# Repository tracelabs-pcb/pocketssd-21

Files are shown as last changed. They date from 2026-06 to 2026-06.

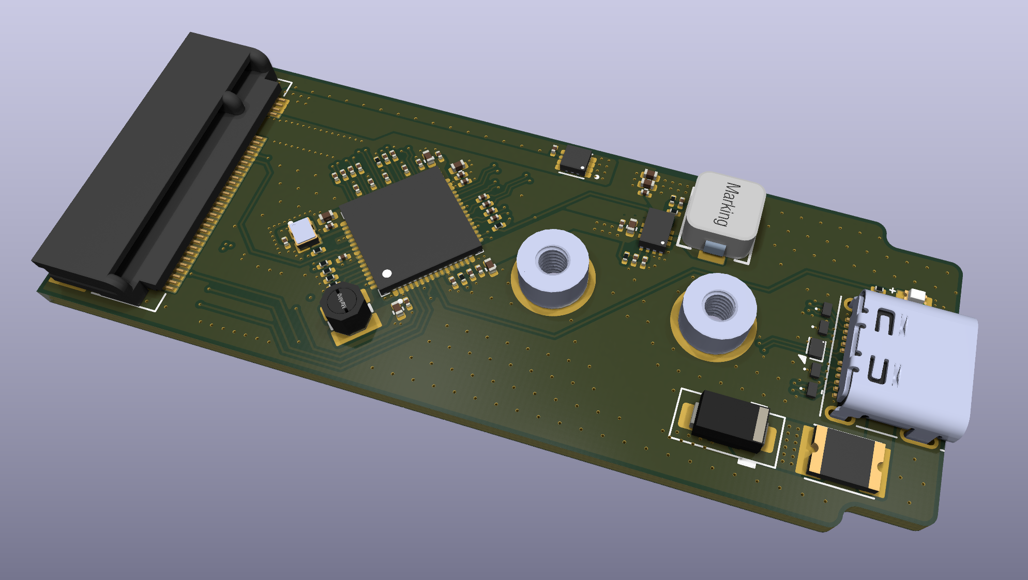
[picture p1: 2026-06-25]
screenshots/3D View Pocket SSD.png

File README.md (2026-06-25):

# PocketSSD-21 — Kompakter USB 3.2 Gen2 NVMe Adapter

**Status: PCB-Design abgeschlossen — unbestückt**  
**Tool:** KiCad | **Layer:** 6-Layer | **Hersteller-ready:** Ja

---

## Projektbeschreibung

Kompakter USB 3.2 Gen2 zu NVMe M.2 Bridge-Adapter auf Basis des JMS583.
Designed für maximale Datenrate bei minimaler Baugröße. 
6-Layer-Stackup (JLC06161H-1080) für saubere Signalintegrität auf 
USB 3.2 Gen2 SuperSpeed+ und PCIe-Leiterbahnen.

**Besonderheiten:**
- USB 3.2 Gen2 (10 Gbit/s) über USB-C
- NVMe M.2 (PCIe Gen3 ×2) Unterstützung
- JMS583 Bridge-Controller
- Differentielle Paare mit kontrollierter Impedanz
- Kompaktes Format, direkt steckbar

---

## Hardware

| Komponente | Beschreibung |
|---|---|
| Bridge-Controller | JMS583 (USB 3.2 Gen2 ↔ PCIe Gen3 ×2) |
| Schnittstelle Host | USB-C (USB 3.2 Gen2, 10 Gbit/s) |
| Schnittstelle Storage | M.2 Key-M (NVMe, PCIe Gen3 ×2) |
| Stackup | 6-Layer (JLC06161H-1080) |
| Tool | KiCad |

---

## PCB

- 6-Layer Stackup für kontrollierte Impedanz
- Differentielle Paare (USB SS+/−, PCIe TX/RX) mit Längen-Matching
- Dedizierte GND-Planes zur Schirmung
- Hierarchisches Schematic über fünf Sheets

---

## Ausschlüsse

Portfolioprojekt — kein Serienprodukt, kein CE/EMV.

---

## Dateien in diesem Repository

- `/kicad/` — KiCad Projektdateien
- `/screenshots/` — PCB- und Schematic-Ansichten

---

> Entwickelt von [Shawn Schneider](https://tracelabs-pcb.de)  
> — PCB-Design & Lötservice, Wolfsburg

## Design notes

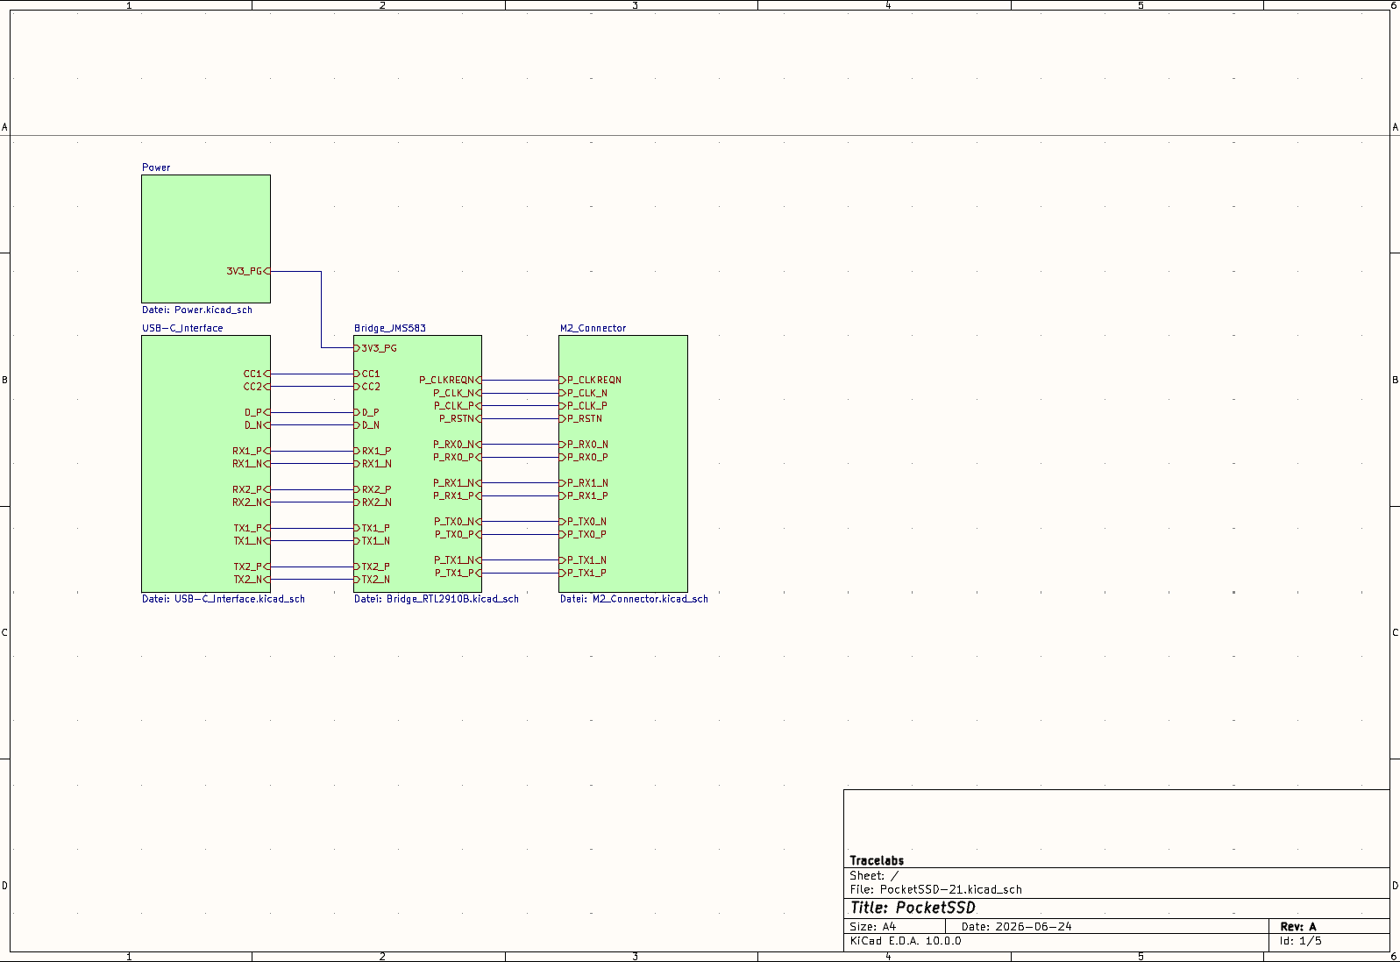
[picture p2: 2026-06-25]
screenshots/Top-Level-Schematic Pocket SSD.png

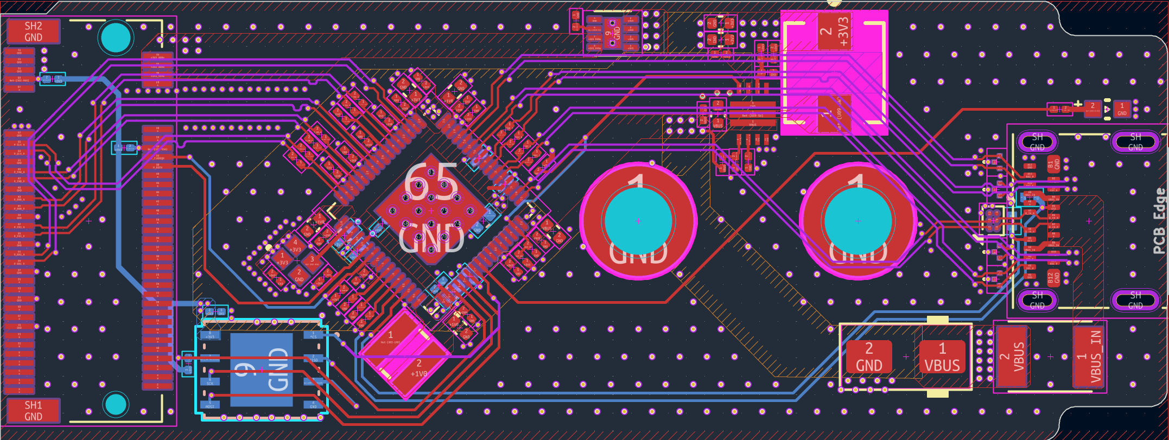
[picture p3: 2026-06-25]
screenshots/PCB Pocket SSD.png

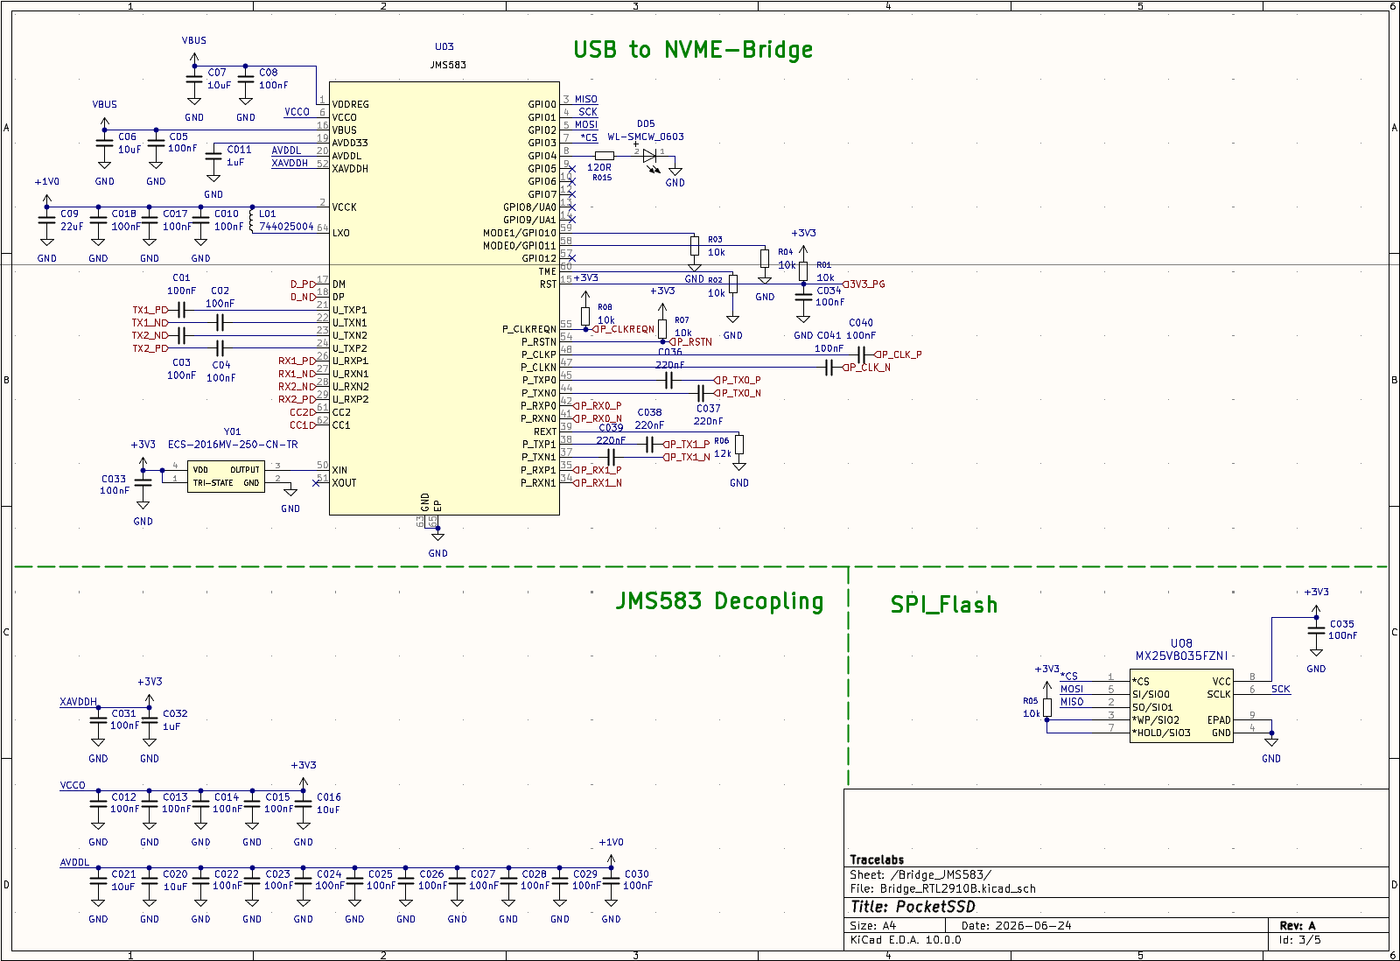
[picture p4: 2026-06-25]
screenshots/Hierarchal Sheet USB-NVMe-Bridge.png

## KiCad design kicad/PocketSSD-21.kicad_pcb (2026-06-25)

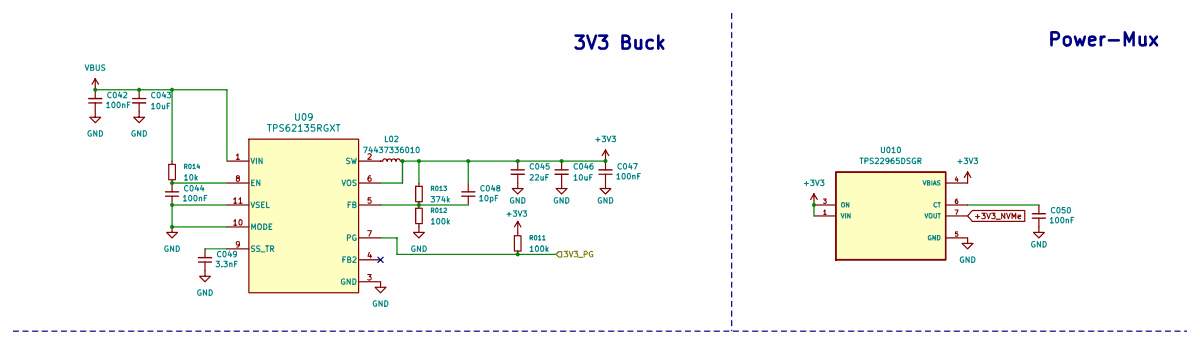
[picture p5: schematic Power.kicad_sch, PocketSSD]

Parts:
C042, C044, C047, C050: 100nF; C_0201_0603Metric
C043, C046: 10uF; C_0402_1005Metric
C045: 22uF; C_0402_1005Metric
C048: 10pF; C_0201_0603Metric
C049: 3.3nF; C_0201_0603Metric
L02: 74437336010; WE-LHMI_5030
R011, R012: 100k; R_0201_0603Metric
R013: 374k; R_0201_0603Metric
R014: 10k; R_0201_0603Metric
U09: TPS62135RGXT; RGX0011A
U010: TPS22965DSGR; SON50P200X200X80-9N

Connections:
+3V3: C045.1, C046.1, C047.2, C048.2, L02.2, R011.1, R013.1, U09.6 (VOS), U010.1 (VIN), U010.2 (VIN), U010.3 (ON), U010.4 (VBIAS); also elsewhere on the board
+3V3_NVMe: U010.7 (VOUT), U010.8 (VOUT); also elsewhere on the board
/Bridge_JMS583/3V3_PG: R011.2, U09.7 (PG); also elsewhere on the board
GND: C042.1, C043.2, C044.1, C045.2, C046.2, C047.1, C049.1, C050.1, R012.2, U09.3 (GND), U09.10 (MODE), U09.11 (VSEL), U010.5 (GND), U010.9 (GND), U010.9_1 (GND), U010.9_2 (GND); also elsewhere on the board
unnamed: C044.2, R014.2, U09.8 (EN)
unnamed: C048.1, R012.1, R013.2, U09.5 (FB)
unnamed: C049.2, U09.9 (SS_TR)
unnamed: L02.1, U09.2 (SW)
unnamed: C050.2, U010.6 (CT)
VBUS: C042.2, C043.1, R014.1, U09.1 (VIN); also elsewhere on the board

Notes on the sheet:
Power-Mux
3V3 Buck

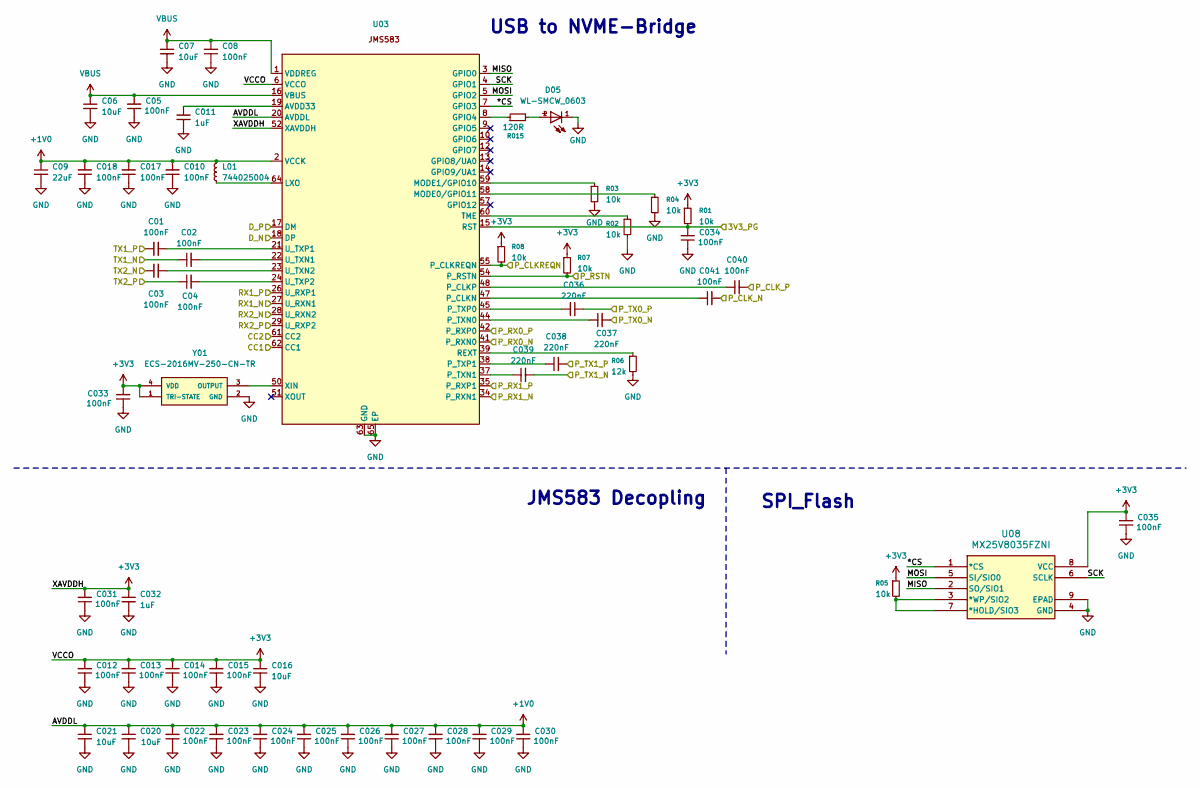
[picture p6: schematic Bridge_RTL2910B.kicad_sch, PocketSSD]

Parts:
C01, C02, C03, C04, C05, C08, C010, C012, C013, C014, C015, C017, C018, C022, C023, C024, C025, C026, C027, C028, C029, C030, C031, C033, C034, C035, C040, C041: 100nF; C_0201_0603Metric
C06, C07, C016, C020, C021: 10uF; C_0402_1005Metric
C09: 22uF; C_0402_1005Metric
C011, C032: 1uF; C_0402_1005Metric
C036, C037, C038, C039: 220nF; C_0201_0603Metric
D05: WL-SMCW_0603
L01: 744025004; WE-TPC_2828
R01, R02, R03, R04, R05, R07, R08: 10k; R_0201_0603Metric
R06: 12k; R_0201_0603Metric
R015: 120R; R_0201_0603Metric
U03: IC_KSZ8794CNXCC-TR
U08: MX25V8035FZNI; WSON8_6X5_MAC
Y01: ECS-2016MV-250-CN-TR; OSC_ECS-1618-300-BN-TR

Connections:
+1V0: C09.1, C010.2, C017.2, C018.2, C020.1, C021.1, C022.2, C023.2, C024.2, C025.2, C026.2, C027.2, C028.2, C029.2, C030.2, L01.2, U03.2 (VCCK), U03.20 (AVDDL), U03.25 (U_AVDDL), U03.30 (U_AVDDL), U03.31 (VCCK), U03.33 (P_AVDDL), U03.36 (P_AVDDL), U03.40 (P_AVDDL), U03.43 (P_AVDDL), U03.46 (C_AVDDL), U03.49 (P_AVDDL), U03.53 (VCCK)
+3V3: C012.2, C013.2, C014.2, C015.2, C016.1, C031.2, C032.1, C033.2, C035.2, R01.1, R05.1, R07.1, R08.1, U03.6 (VCCO), U03.11 (VCCO), U03.32 (VCCO), U03.52 (XAVDDH), U03.56 (VCCO), U08.8 (VCC), Y01.1 (TRI-STATE), Y01.4 (VDD); also elsewhere on the board
/Bridge_JMS583/3V3_PG: C034.2, R01.2, U03.15 (RST); also elsewhere on the board
/Bridge_JMS583/*CS: U03.7 (GPIO3), U08.1 (*CS)
/Bridge_JMS583/CC1: U03.62 (CC1); also elsewhere on the board
/Bridge_JMS583/CC2: U03.61 (CC2); also elsewhere on the board
/Bridge_JMS583/D_N: U03.18 (DP); also elsewhere on the board
/Bridge_JMS583/D_P: U03.17 (DM); also elsewhere on the board
/Bridge_JMS583/MISO: U03.3 (GPIO0), U08.2 (SO/SIO1)
/Bridge_JMS583/MOSI: U03.5 (GPIO2), U08.5 (SI/SIO0)
/Bridge_JMS583/P_CLKREQN: R08.2, U03.55 (P_CLKREQN); also elsewhere on the board
/Bridge_JMS583/P_CLK_N: C041.2; also elsewhere on the board
/Bridge_JMS583/P_CLK_P: C040.2; also elsewhere on the board
/Bridge_JMS583/P_RSTN: R07.2, U03.54 (P_RSTN); also elsewhere on the board
/Bridge_JMS583/P_RX0_N: U03.41 (P_RXN0); also elsewhere on the board
/Bridge_JMS583/P_RX0_P: U03.42 (P_RXP0); also elsewhere on the board
/Bridge_JMS583/P_RX1_N: U03.34 (P_RXN1); also elsewhere on the board
/Bridge_JMS583/P_RX1_P: U03.35 (P_RXP1); also elsewhere on the board
/Bridge_JMS583/P_TX0_N: C037.2; also elsewhere on the board
/Bridge_JMS583/P_TX0_P: C036.2; also elsewhere on the board
/Bridge_JMS583/P_TX1_N: C039.2; also elsewhere on the board
/Bridge_JMS583/P_TX1_P: C038.2; also elsewhere on the board
/Bridge_JMS583/RX1_N: U03.27 (U_RXN1); also elsewhere on the board
/Bridge_JMS583/RX1_P: U03.26 (U_RXP1); also elsewhere on the board
/Bridge_JMS583/RX2_N: U03.28 (U_RXN2); also elsewhere on the board
/Bridge_JMS583/RX2_P: U03.29 (U_RXP2); also elsewhere on the board
/Bridge_JMS583/SCK: U03.4 (GPIO1), U08.6 (SCLK)
/Bridge_JMS583/TX1_N: C02.1; also elsewhere on the board
/Bridge_JMS583/TX1_P: C01.1; also elsewhere on the board
/Bridge_JMS583/TX2_N: C03.1; also elsewhere on the board
/Bridge_JMS583/TX2_P: C04.1; also elsewhere on the board
GND: C05.1, C06.2, C07.2, C08.1, C09.2, C010.1, C011.2, C012.1, C013.1, C014.1, C015.1, C016.2, C017.1, C018.1, C020.2, C021.2, C022.1, C023.1, C024.1, C025.1, C026.1, C027.1, C028.1, C029.1, C030.1, C031.1, C032.2, C033.1, C034.1, C035.1, D05.1, R02.2, R03.2, R04.2, R06.2, U03.63 (GND), U03.65 (EP), U03.66 (GND), U03.67 (GND), U03.68 (GND), U03.69 (GND), U03.70 (GND), U03.71 (GND), U03.72 (GND), U03.73 (GND), U03.74 (GND), U03.75 (GND), U03.76 (GND), U03.77 (GND), U03.78 (GND), U03.79 (GND), U03.80 (GND), U03.81 (GND), U08.4 (GND), U08.9 (EPAD), Y01.2 (GND); also elsewhere on the board
unnamed: D05.2, R015.2
unnamed: C011.1, U03.19 (AVDD33)
unnamed: R015.1, U03.8 (GPIO4)
unnamed: L01.1, U03.64 (LXO)
unnamed: R04.1, U03.58 (MODE0/GPIO11)
unnamed: R03.1, U03.59 (MODE1/GPIO10)
unnamed: C041.1, U03.47 (P_CLKN)
unnamed: C040.1, U03.48 (P_CLKP)
unnamed: C037.1, U03.44 (P_TXN0)
unnamed: C039.1, U03.37 (P_TXN1)
unnamed: C036.1, U03.45 (P_TXP0)
unnamed: C038.1, U03.38 (P_TXP1)
unnamed: R06.1, U03.39 (REXT)
unnamed: R02.1, U03.60 (TME)
unnamed: C02.2, U03.22 (U_TXN1)
unnamed: C03.2, U03.23 (U_TXN2)
unnamed: C01.2, U03.21 (U_TXP1)
unnamed: C04.2, U03.24 (U_TXP2)
unnamed: U03.50 (XIN), Y01.3 (OUTPUT)
unnamed: R05.2, U08.3 (*WP/SIO2), U08.7 (*HOLD/SIO3)
VBUS: C05.2, C06.1, C07.1, C08.2, U03.1 (VDDREG), U03.16 (VBUS); also elsewhere on the board

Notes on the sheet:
JMS583 Decopling
USB to NVME-Bridge
SPI_Flash

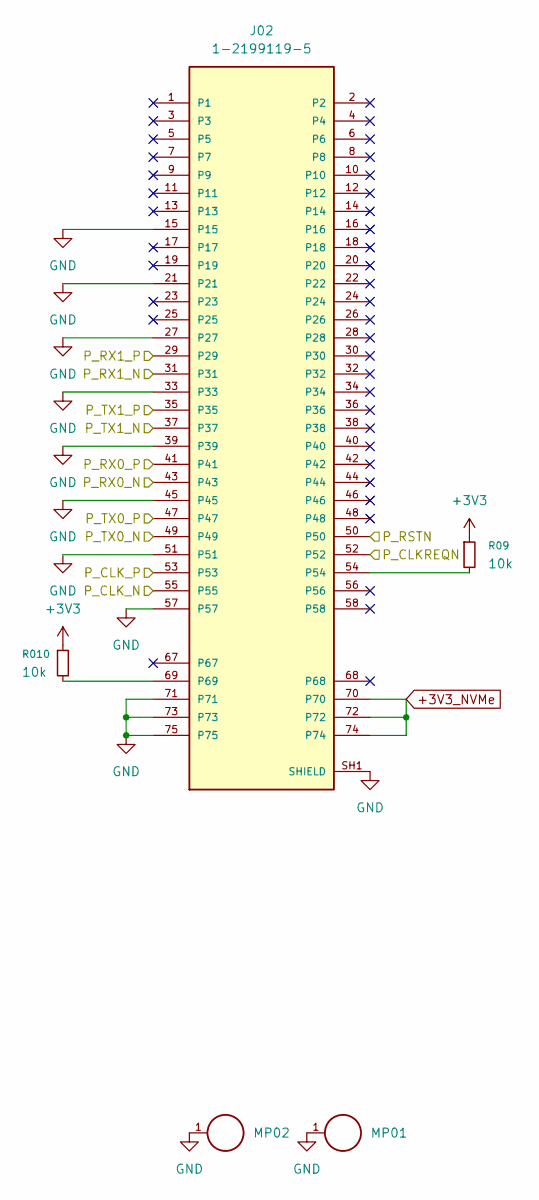
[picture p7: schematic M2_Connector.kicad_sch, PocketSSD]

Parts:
J02: 1-2199119-5; TE_1-2199119-5; DigiKey_Part_Number A115902CT-ND
MP01, MP02: M2.5 x 2.5mm; WA-SMSI_9774025151; PART-NUMBER 9774025151R
R09, R010: 10k; R_0201_0603Metric

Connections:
+3V3: R09.1, R010.1; also elsewhere on the board
+3V3_NVMe: J02.70, J02.72, J02.74; also elsewhere on the board
/Bridge_JMS583/P_CLKREQN: J02.52; also elsewhere on the board
/Bridge_JMS583/P_CLK_N: J02.55; also elsewhere on the board
/Bridge_JMS583/P_CLK_P: J02.53; also elsewhere on the board
/Bridge_JMS583/P_RSTN: J02.50; also elsewhere on the board
/Bridge_JMS583/P_RX0_N: J02.43; also elsewhere on the board
/Bridge_JMS583/P_RX0_P: J02.41; also elsewhere on the board
/Bridge_JMS583/P_RX1_N: J02.31; also elsewhere on the board
/Bridge_JMS583/P_RX1_P: J02.29; also elsewhere on the board
/Bridge_JMS583/P_TX0_N: J02.49; also elsewhere on the board
/Bridge_JMS583/P_TX0_P: J02.47; also elsewhere on the board
/Bridge_JMS583/P_TX1_N: J02.37; also elsewhere on the board
/Bridge_JMS583/P_TX1_P: J02.35; also elsewhere on the board
GND: J02.15, J02.21, J02.27, J02.33, J02.39, J02.45, J02.51, J02.57, J02.71, J02.73, J02.75, J02.SH1 (SHIELD), J02.SH2 (SHIELD), MP01.1, MP02.1; also elsewhere on the board
unnamed: J02.54, R09.2
unnamed: J02.69, R010.2

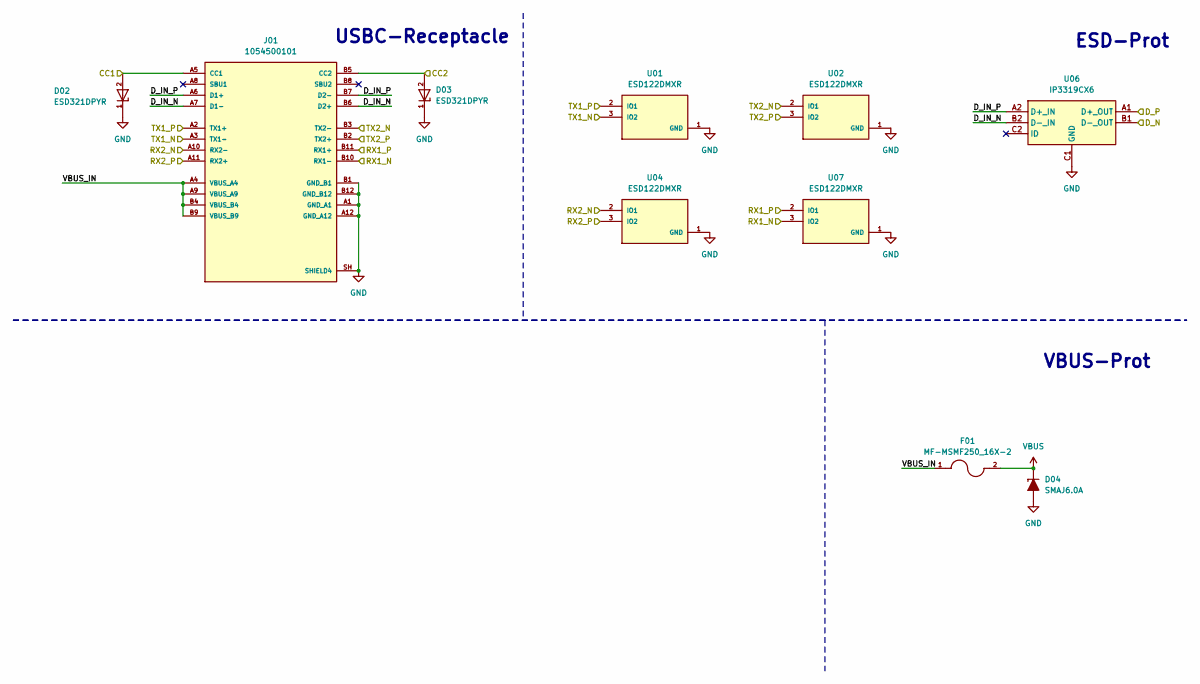
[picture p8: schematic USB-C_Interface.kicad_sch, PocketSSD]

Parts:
D02, D03: ESD321DPYR; TVS_ESD321DPYR; PARTREV B
D04: SMAJ6.0A; D_SMA
F01: MF-MSMF250_16X-2; FUSER_MF-MSMF250_16X-2
J01: 1054500101; USB_C_Receptacle_Molex_105450-0101; PARTREV A7
U01, U02, U04, U07: ESD122DMXR; IC_ESD122DMXR; PARTREV A
U06: IP3319CX6; WLCSP-6_1.4x1.0mm_P0.4mm

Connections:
/Bridge_JMS583/CC1: D02.2, J01.A5 (CC1); also elsewhere on the board
/Bridge_JMS583/CC2: D03.2, J01.B5 (CC2); also elsewhere on the board
/Bridge_JMS583/D_N: U06.B1 (D-_OUT); also elsewhere on the board
/Bridge_JMS583/D_P: U06.A1 (D+_OUT); also elsewhere on the board
/Bridge_JMS583/RX1_N: J01.B10 (RX1-), U07.3 (IO2); also elsewhere on the board
/Bridge_JMS583/RX1_P: J01.B11 (RX1+), U07.2 (IO1); also elsewhere on the board
/Bridge_JMS583/RX2_N: J01.A10 (RX2-), U04.2 (IO1); also elsewhere on the board
/Bridge_JMS583/RX2_P: J01.A11 (RX2+), U04.3 (IO2); also elsewhere on the board
/Bridge_JMS583/TX1_N: J01.A3 (TX1-), U01.3 (IO2); also elsewhere on the board
/Bridge_JMS583/TX1_P: J01.A2 (TX1+), U01.2 (IO1); also elsewhere on the board
/Bridge_JMS583/TX2_N: J01.B3 (TX2-), U02.2 (IO1); also elsewhere on the board
/Bridge_JMS583/TX2_P: J01.B2 (TX2+), U02.3 (IO2); also elsewhere on the board
/USB-C_Interface/D_IN_N: J01.A7 (D1-), J01.B6 (D2+), U06.B2 (D-_IN)
/USB-C_Interface/D_IN_P: J01.A6 (D1+), J01.B7 (D2-), U06.A2 (D+_IN)
/USB-C_Interface/VBUS_IN: F01.1, J01.A4 (VBUS_A4), J01.A9 (VBUS_A9), J01.B4 (VBUS_B4), J01.B9 (VBUS_B9)
GND: D02.1, D03.1, D04.2 (A), J01.A1 (GND_A1), J01.A12 (GND_A12), J01.B1 (GND_B1), J01.B12 (GND_B12), J01.SH (SHIELD4), U01.1 (GND), U02.1 (GND), U04.1 (GND), U06.C1 (GND), U07.1 (GND); also elsewhere on the board
VBUS: D04.1 (K), F01.2; also elsewhere on the board

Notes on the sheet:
VBUS-Prot
ESD-Prot
USBC-Receptacle

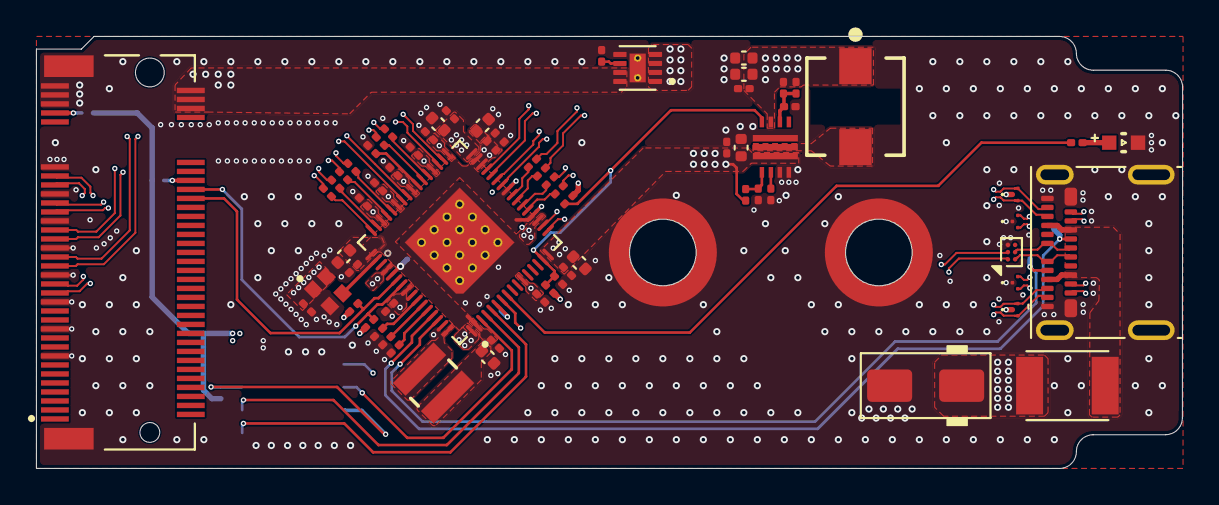
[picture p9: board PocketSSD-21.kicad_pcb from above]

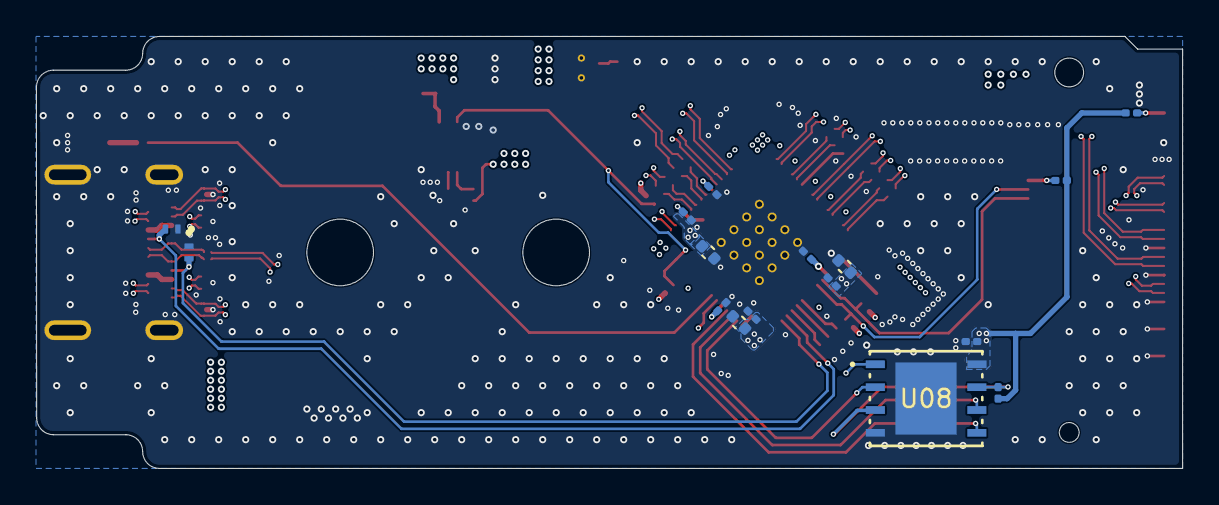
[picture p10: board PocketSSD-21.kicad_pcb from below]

Board: 6 copper layers, 63.7 x 24.0 mm, 85 parts (16 on the bottom side), 64 nets.

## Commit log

2026-06-25 Add kicad folder
2026-06-25 Add KiCad project files
    [Bridge_RTL2910B.kicad_sch, Flash_Config.kicad_sch, M2_Connector.kicad_sch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]
